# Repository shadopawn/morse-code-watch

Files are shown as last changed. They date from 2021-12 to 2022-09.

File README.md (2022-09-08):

```
                                                                                        
                                                                                        
                ______   ______       ______       ______               ______   ______ 
               /_____/  /_____/      /_____/      /_____/              /_____/  /_____/ 
                                              /\           /\      /\                   
                                              \/           \/      \/                   
```

# Morse Code Watch

The `Morse Code Watch` is quite simply a watch that tells you the time in morse code. Touch the top of the watch and it will vibrate out the current time in Morse code.

<p align="center">
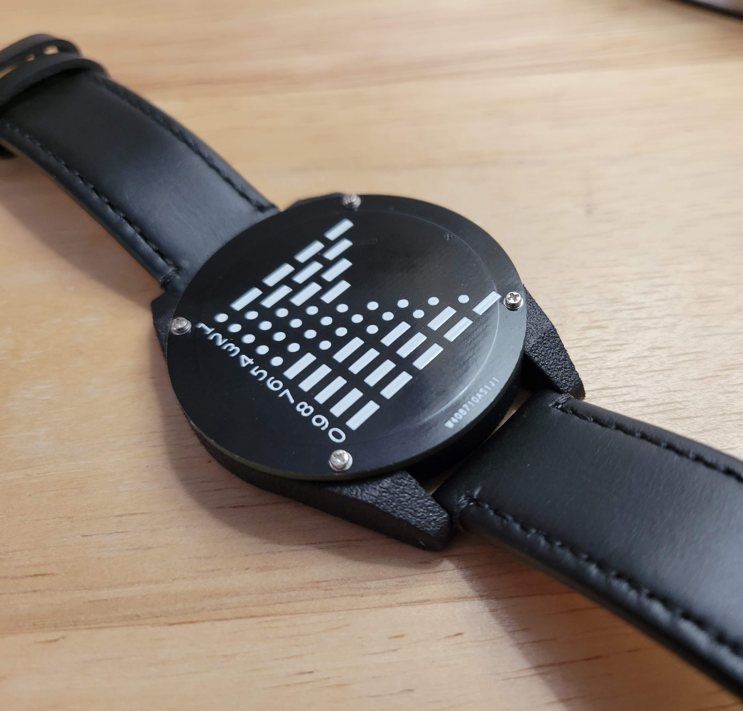
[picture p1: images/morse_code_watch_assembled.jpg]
    
    
</p>

<p align="middle">
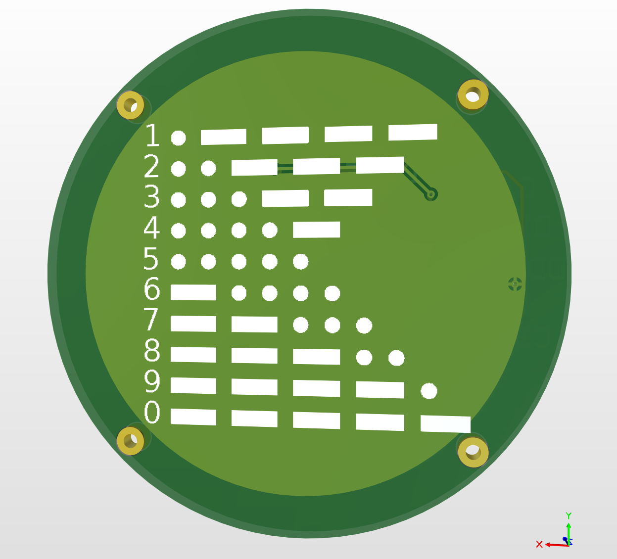
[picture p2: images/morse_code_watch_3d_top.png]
    
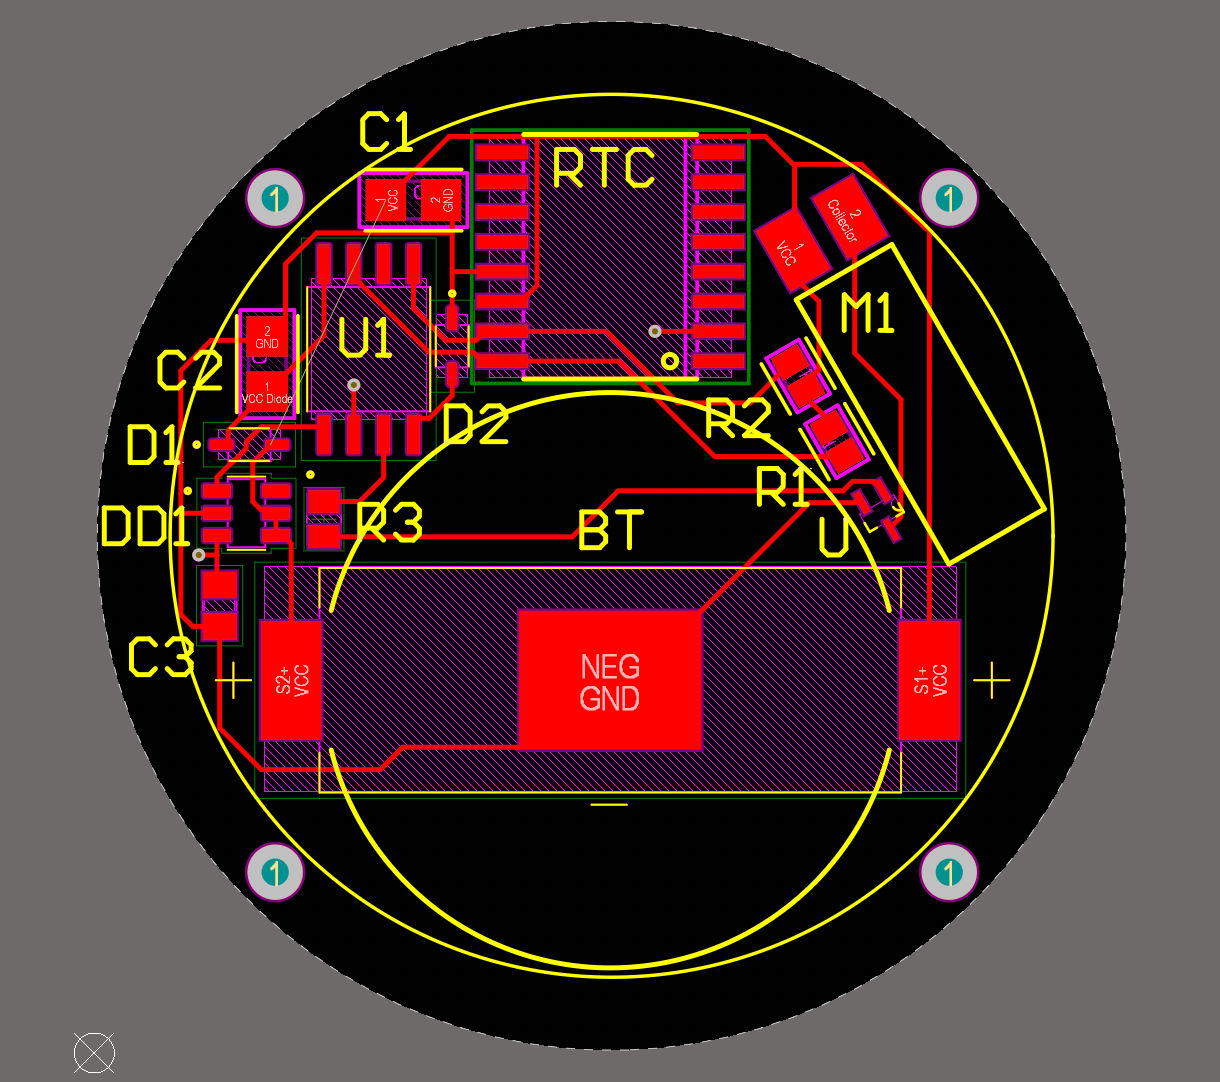
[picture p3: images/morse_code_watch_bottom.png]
    
</p>

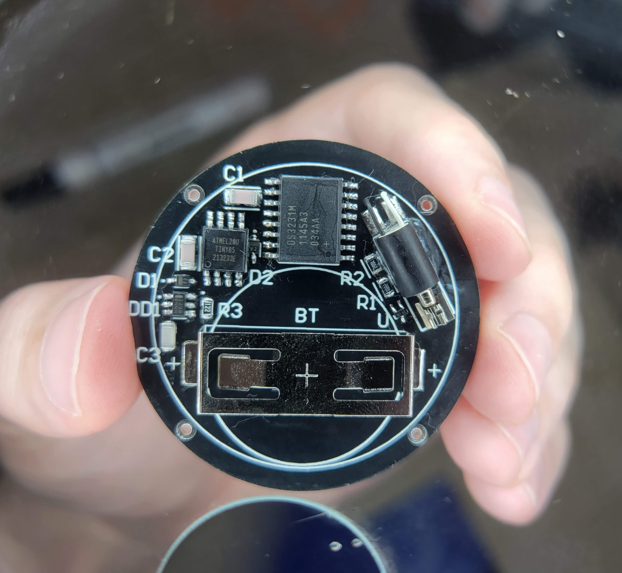
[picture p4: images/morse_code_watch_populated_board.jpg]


<p align="middle">
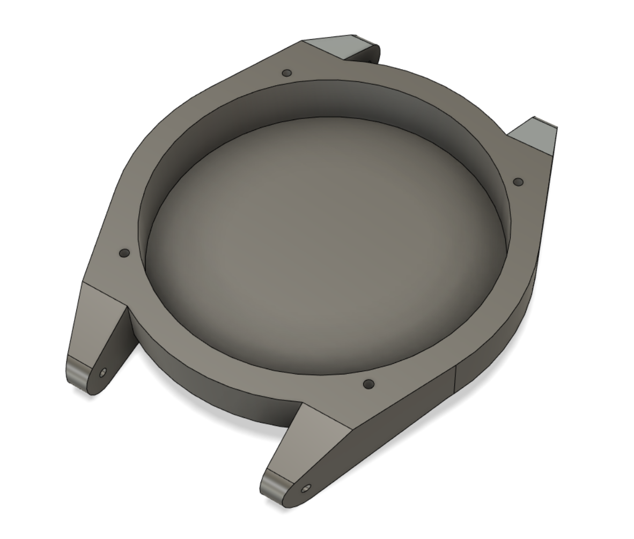
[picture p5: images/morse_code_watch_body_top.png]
    
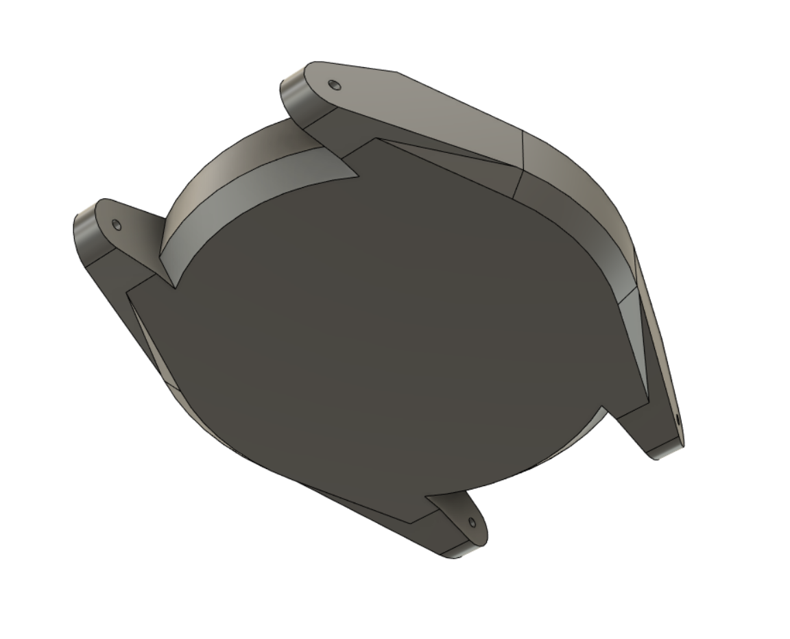
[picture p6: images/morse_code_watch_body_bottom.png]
    
</p>

## Block Diagram
```mermaid
flowchart TB
    μController <--> RTC(Real Time Clock)
    B(Battery) --> μController
    CS(Capacitive Sensor) --> μController
    μController --> VM(Vibration Motor)
```

## Dependencies

The software for this project only has one explicit dependency [JChristensen/DS3232RTC](https://github.com/JChristensen/DS3232RTC)
implicitly the `DS3232RTC` library written by *JChristensen* includes a time library it was designed to work with [PaulStoffregen/Time](https://github.com/PaulStoffregen/Time).

This dependency can be added via Arduino's library manager follow this [guide](https://docs.arduino.cc/software/ide-v1/tutorials/installing-libraries).

## Setup Guides
- [Add Attiny85 board to Arduino IDE](http://highlowtech.org/?p=1695)
- [Tiny AVR Programmer Hookup](https://learn.sparkfun.com/tutorials/tiny-avr-programmer-hookup-guide/all)
- [Software Serial on Attiny85](https://jloh02.github.io/projects/connecting-attiny85-serial-monitor/)

## μController Pinout

Specifically this project uses an ATtiny85 as its μController.

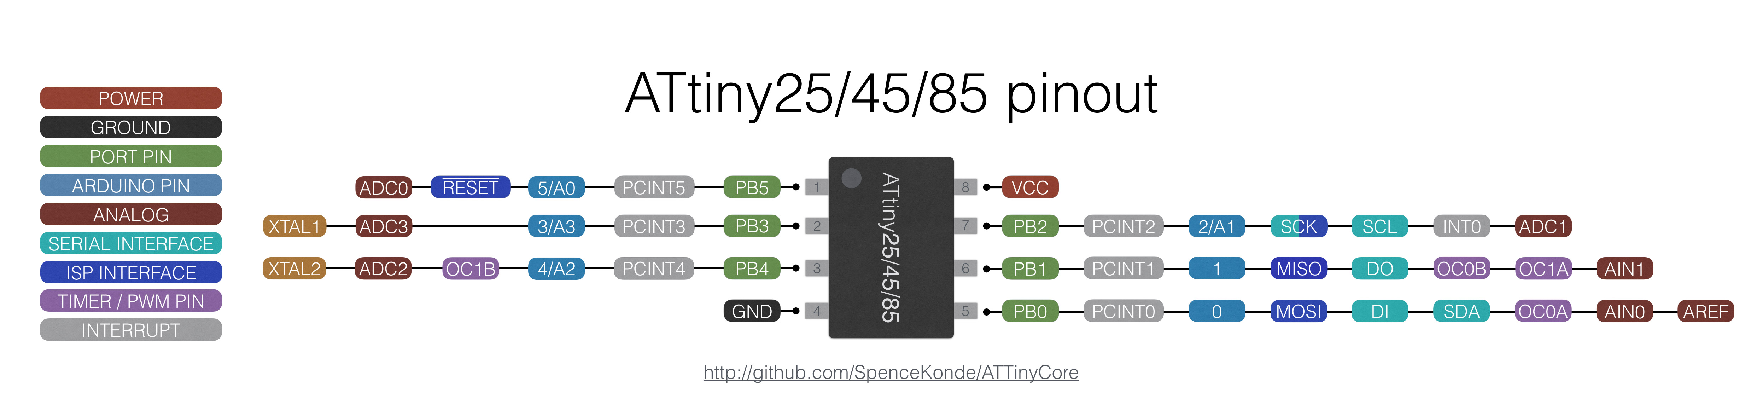
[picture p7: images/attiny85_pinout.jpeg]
Attiny85 pinout


## Morse Code

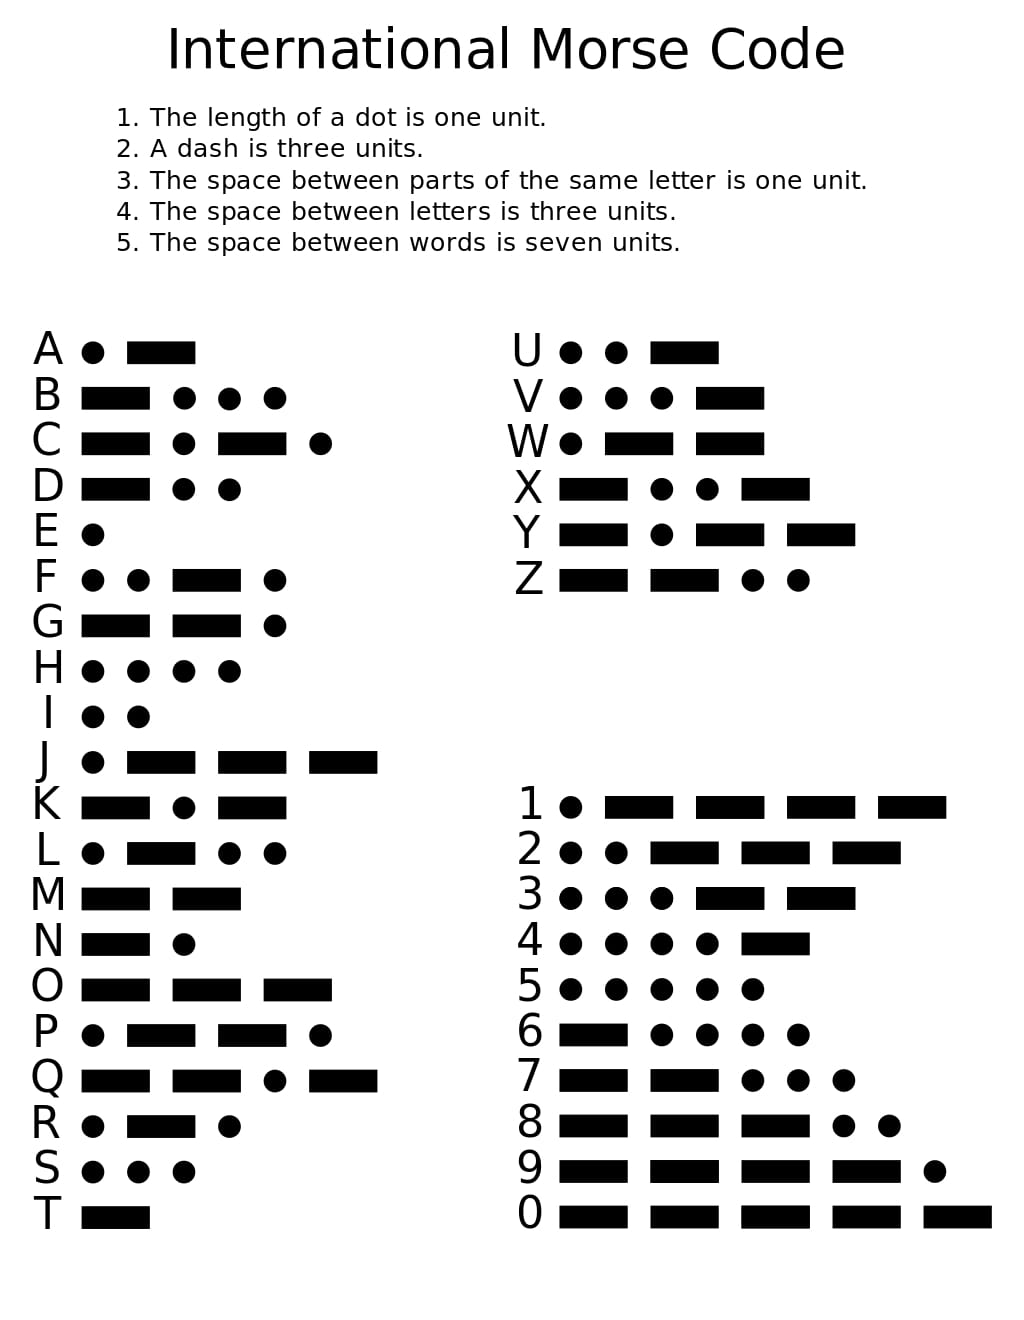
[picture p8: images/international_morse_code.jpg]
Morse Code


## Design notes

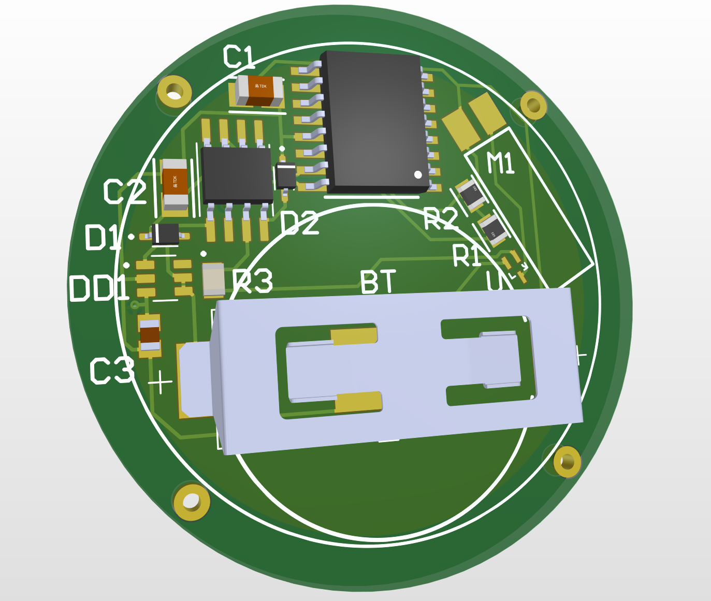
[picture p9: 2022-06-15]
images/morse_code_watch_3d_bottom.png

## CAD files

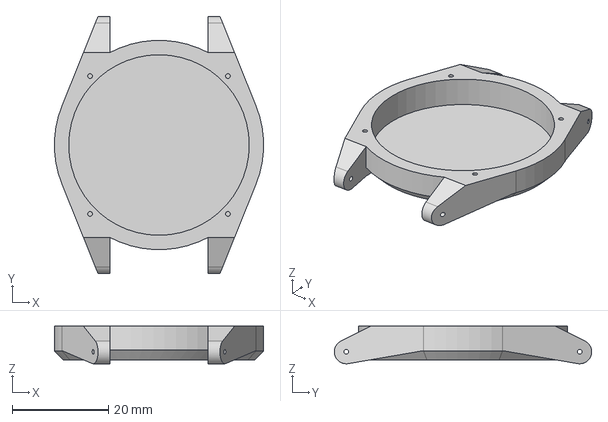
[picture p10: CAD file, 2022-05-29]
cad/morse_code_watch_body/morse_code_watch_body.step
43.5 x 53.6 x 7.83 mm

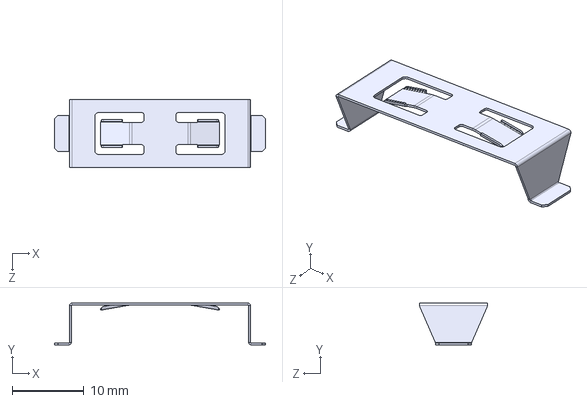
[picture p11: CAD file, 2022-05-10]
pcb/external_componenets/BC-2005/BC-2005.STEP
29.5 x 5.84 x 9.56 mm

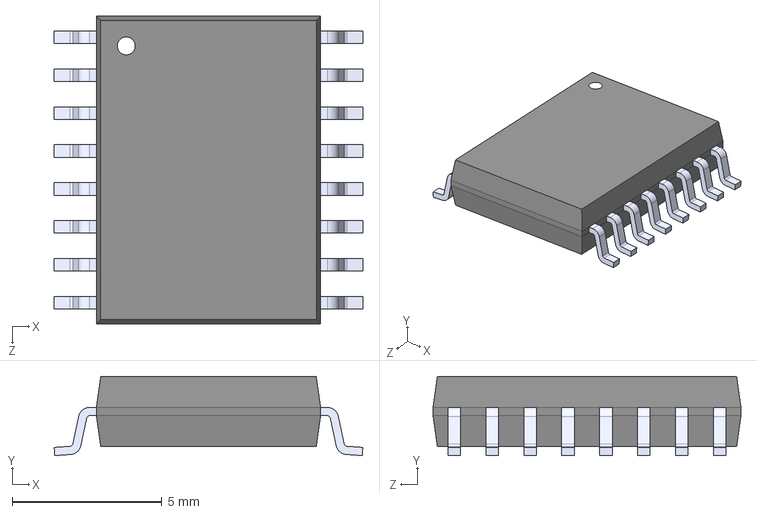
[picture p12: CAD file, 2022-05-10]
pcb/external_componenets/DS3231/DS3231.STEP
10.3 x 2.65 x 10.3 mm

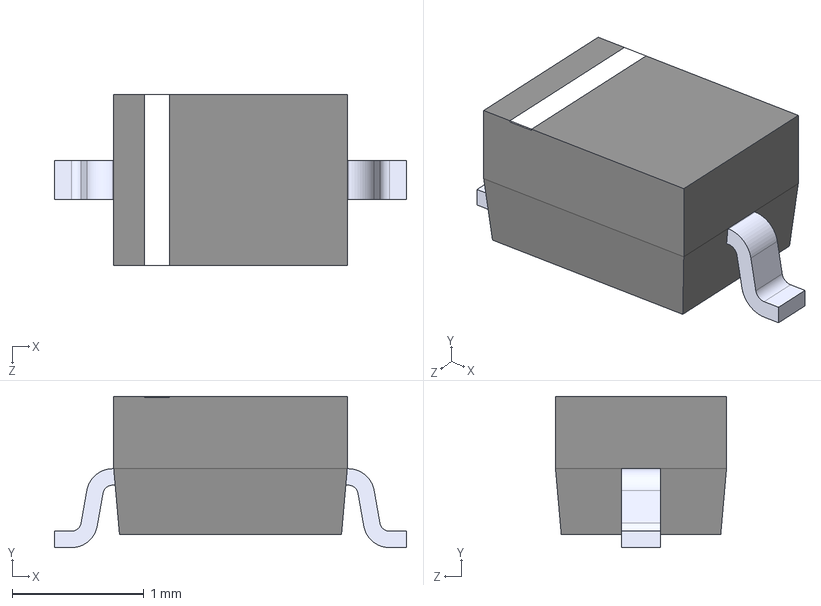
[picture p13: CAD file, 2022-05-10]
pcb/morse_code_watch/3D_models/PMEG1020EA.STEP
2.67 x 1.15 x 1.30 mm

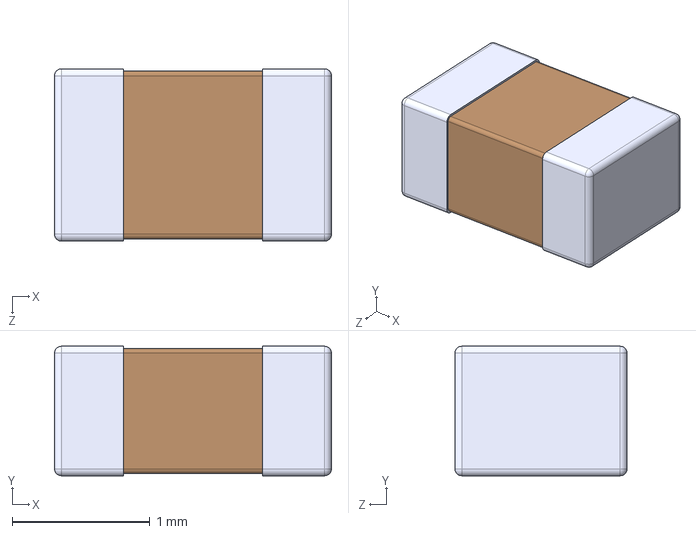
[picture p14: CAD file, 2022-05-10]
pcb/external_componenets/08051A500GAT2A/08051A500GAT2A/08051A500GAT2A.STEP
2.01 x 0.94 x 1.25 mm

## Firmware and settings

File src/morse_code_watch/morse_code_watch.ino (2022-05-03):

#include "morse_clock.h"
#include "vibration_motor.h"
#include "rtc_initializer.h"
#include "attiny_sleep.h"

const int rtcPowerPin = 3;
const int vibrationMotorPin = 4;

ProgrammerStatus programmerStatus;
LowPowerRtc lowPowerRtc(rtcPowerPin);
RtcInitializer rtcInitializer(&programmerStatus, &lowPowerRtc);

VibrationMotor vibrationMotor(vibrationMotorPin);
MorseClock morseClock(&vibrationMotor, &lowPowerRtc);

ATtinySleep attiny;

void setup()
{
    rtcInitializer.setTimeIfProgrammerAttached();

    morseClock.outputTime();

    attiny.sleep();
}

void loop() {}

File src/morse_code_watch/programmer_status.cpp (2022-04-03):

#include "programmer_status.h"

ProgrammerStatus::ProgrammerStatus(int voltageThreshold = 4000)
{
    this->voltageThreshold = voltageThreshold;
}

bool ProgrammerStatus::isProgrammerAttached()
{
    return internalVoltage() > voltageThreshold;
}

int ProgrammerStatus::internalVoltage()
{
    // reads internal 1V1 reference against VCC
    ADMUX = _BV(MUX3) | _BV(MUX2);
    delay(2); // Wait for Vref to settle
    unscaledVoltageReading();
    // discard previous result
    unsigned int reading = unscaledVoltageReading();
    // return voltage in mV
    return ((long)1024 * 1100) / reading;
}

unsigned int ProgrammerStatus::unscaledVoltageReading()
{
    ADCSRA |= _BV(ADSC); // Convert
    while (bit_is_set(ADCSRA, ADSC));
    uint8_t low = ADCL;
    return (ADCH << 8) | low;
}

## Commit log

2021-12-19 Add program to vibrate when sensor touched
2021-12-23 Add trigger for pressing touch sensor
2021-12-23 Fix touch sensor press logic
2021-12-25 Remove brackets from if statement
2021-12-26 Move brackets for loop and setup
2021-12-27 Create touch sensor trigger example
2021-12-28 Change vibration motor pin
2022-01-01 Add guide for attiny85 board setup in arduino
2022-01-08 Add links to low power mode for mcu
2022-01-16 Reorder low power mode links
2022-01-17 Add serial print to time setting
2022-01-17 Break out functions to print date and time
2022-01-18 Remove onTouch function and pin variable
2022-01-22 Add read internal voltage example
2022-01-22 Add required functions to read-internal-voltage.ino
2022-01-22 Add SoftwareSerial to read-internal-voltage.ino
2022-01-22 Specify type of pin in comment
2022-01-22 Add sketch to detect when programmer attached
2022-01-22 Change wording in serial print
2022-01-22 Add printVoltage function
2022-01-22 Print if programmer was not attached
2022-01-22 Change print to println
2022-01-23 Fix bracket position
2022-01-23 Add comment about adc in internalVoltage function
2022-01-24 Set time if programmer attached
2022-01-24 Rename currentRunningTime variable
2022-01-31 Only power rtc when using it
2022-02-05 Change kebab case to snake case
2022-02-05 Add class for morse vibration motor
    [morse_code_watch.ino]
2022-02-05 Revert changes to morse_code_watch.ino
    [morse_code_watch.ino]
2022-02-26 Rename variable with short name
    [programmer_status.cpp]
2022-05-10 Add altium files for pcb
    [08051A500GAT2A.STEP, 08051A500GAT2A.SchLib, ATTINY85-20SU.SchLib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]
2022-05-10 Complete routing excluding touch sensor
    [morse_code_watch.PcbDoc, morse_code_watch.SchDoc]
2022-05-11 Put mounting holes on pcb
    [morse_code_watch.PcbDoc, morse_code_watch.PcbLib, morse_code_watch.SchLib]
2022-05-11 Move via under rtc chip
    [morse_code_watch.PcbDoc]
2022-05-11 Add touch pad on bottom of board
    [morse_code_watch.PcbDoc, morse_code_watch.SchDoc]
2022-05-11 Add morse digits to board
    [morse_code_watch.PcbDoc]
2022-05-12 Export pcb for manufacturing
    [morse_code_watch.PcbDoc, morse_code_watch.PrjPcb]
2022-05-20 Fix diode model direction
    [morse_code_watch.PcbDoc, morse_code_watch.PcbLib]
2022-05-26 Include manufacturing files
    [morse_code_watch.PcbDoc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]
2022-05-29 Export watch body cad file
    [morse_code_watch_body.step]
